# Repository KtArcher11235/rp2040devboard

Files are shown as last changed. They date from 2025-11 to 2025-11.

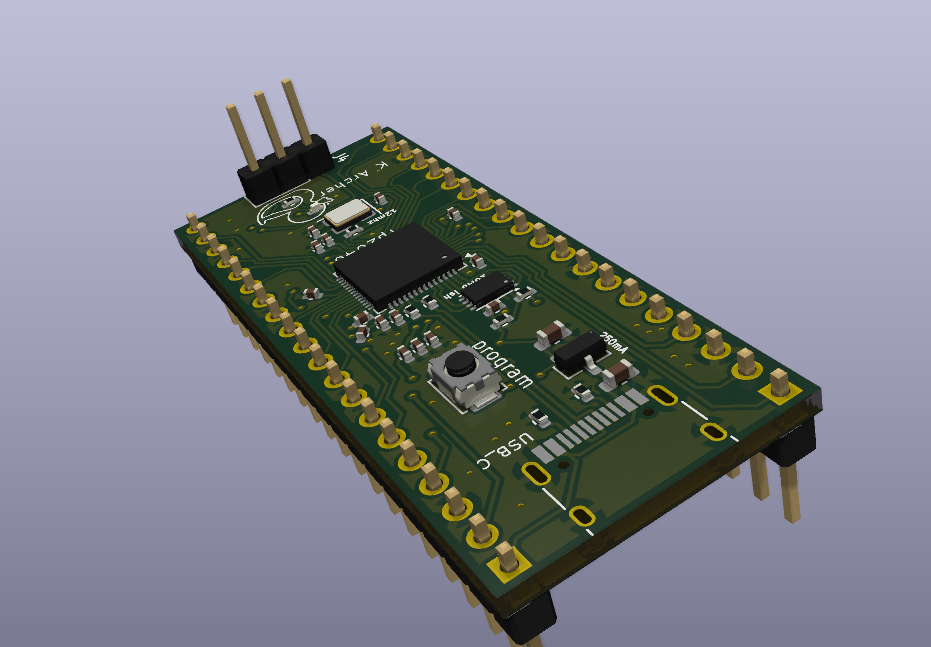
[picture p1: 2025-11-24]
CAD/Screenshot 2025-11-24 150255.png

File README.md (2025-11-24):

# rp2040devboard
a signature devboard based on the rp2040 designed to be as minimal as possible, allowing for expandability through the pins.



## specs
- rp2040
- 16 MiB Flash
- LED on gipo25
- 12 MHz crystal
- USB interface with voltage regulator

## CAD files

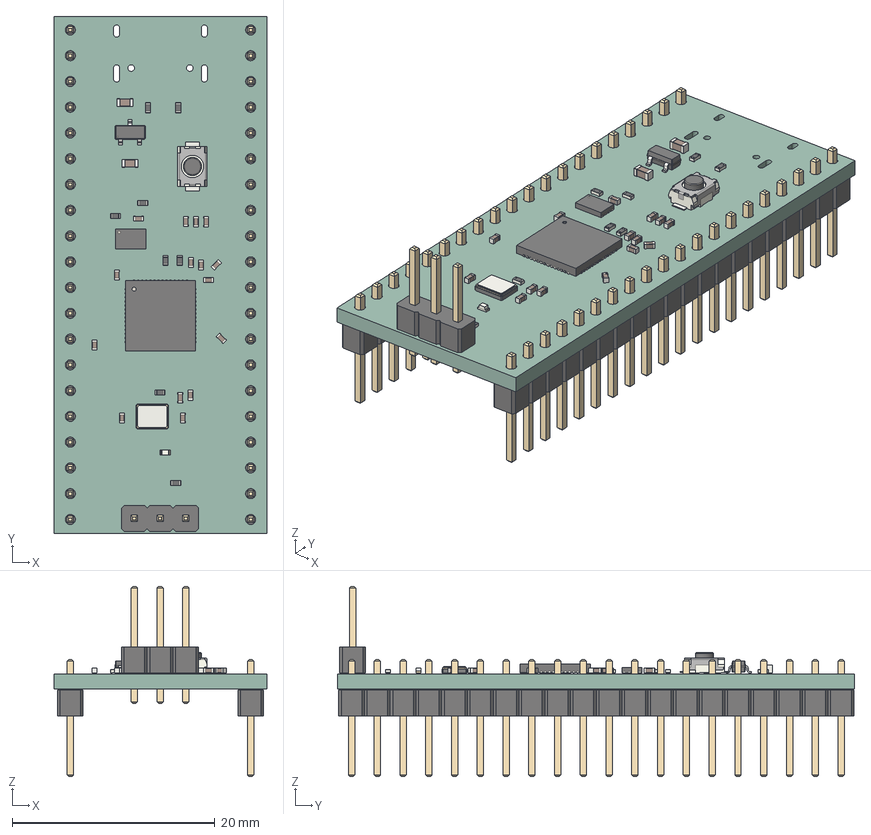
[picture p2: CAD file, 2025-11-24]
CAD/devboard.step
21.0 x 51.0 x 18.8 mm
C_0603_1608Metric x 2
C_0402_1005Metric x 15
LED_0402_1005Metric
SOT-23
R_0402_1005Metric x 8
QFN-56-1EP_7x7mm_P0.4mm_EP3.2x3.2mm
Crystal_SMD_3225-4Pin_3.2x2.5mm
SW_Push_SPST_NO_Alps_SKRK
Winbond_USON-8-1EP_3x2mm_P0.5mm_EP0.2x1.6mm
PinHeader_1x03_P2.54mm_Vertical
PinHeader_1x20_P2.54mm_Vertical x 2
devboard_PCB

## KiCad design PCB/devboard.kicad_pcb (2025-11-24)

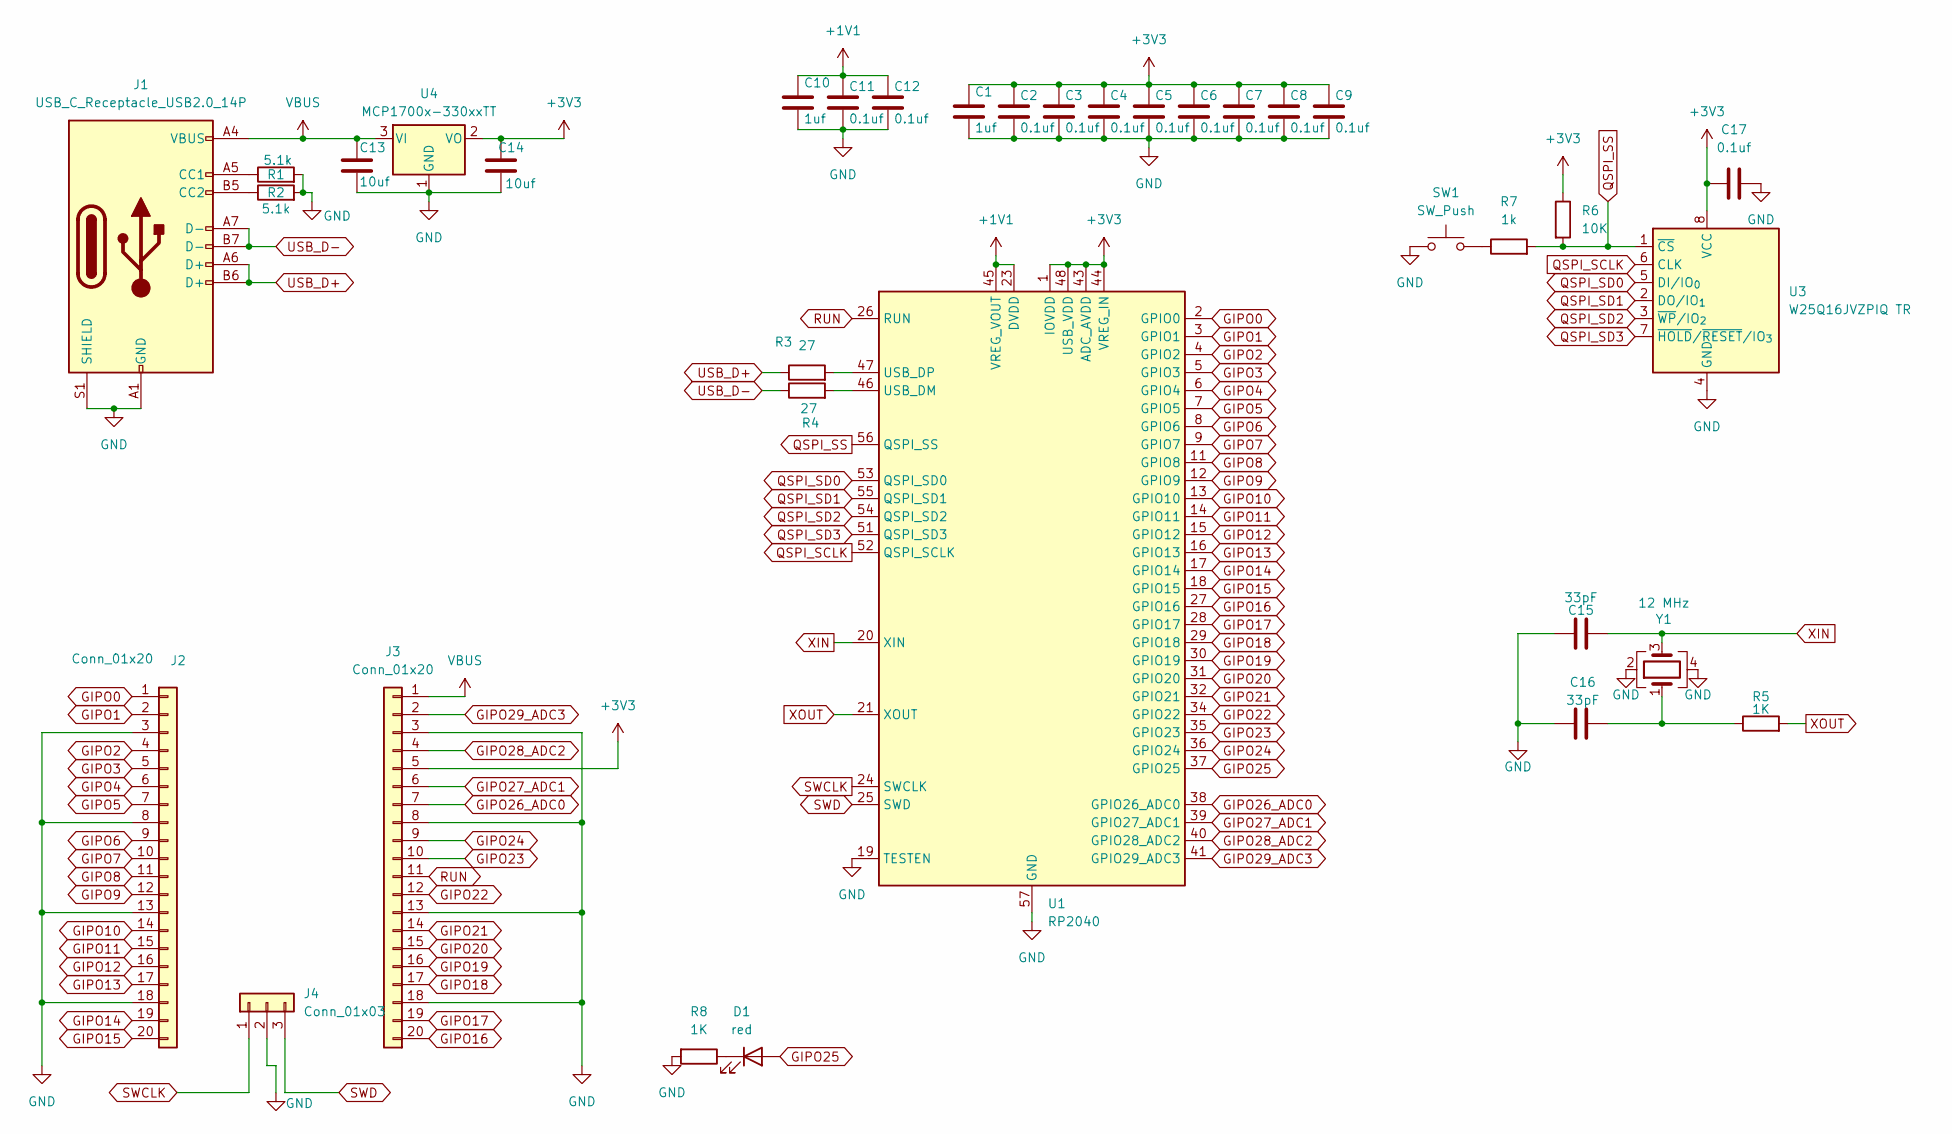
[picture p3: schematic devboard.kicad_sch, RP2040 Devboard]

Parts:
C1, C10: 1uf; C_0402_1005Metric
C2, C3, C4, C5, C6, C7, C8, C9, C11, C12, C17: 0.1uf; C_0402_1005Metric
C13, C14: 10uf; C_0603_1608Metric
C15, C16: 33pF; C_0402_1005Metric
D1: red; LED_0402_1005Metric
J1: USB_C_Receptacle_USB2.0_14P; USB_C_Receptacle_HRO_TYPE-C-31-M-12
J2, J3: Conn_01x20; PinHeader_1x20_P2.54mm_Vertical
J4: Conn_01x03; PinHeader_1x03_P2.54mm_Vertical
R1, R2: 5.1k; R_0402_1005Metric
R3, R4: 27; R_0402_1005Metric
R5, R8: 1K; R_0402_1005Metric
R6: 10K; R_0402_1005Metric
R7: 1k; R_0402_1005Metric
SW1: SW_Push; SW_Push_SPST_NO_Alps_SKRK
U1: RP2040; QFN-56-1EP_7x7mm_P0.4mm_EP3.2x3.2mm
U3: W25Q16JVZPIQ TR; Winbond_USON-8-1EP_3x2mm_P0.5mm_EP0.2x1.6mm
U4: MCP1700x-330xxTT; SOT-23
Y1: 12 MHz; Crystal_SMD_3225-4Pin_3.2x2.5mm

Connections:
+1V1: C10.1, C11.1, C12.1, U1.23 (DVDD), U1.45 (VREG_VOUT), U1.50 (DVDD)
+3V3: C1.1, C2.1, C3.1, C4.1, C5.1, C6.1, C7.1, C8.1, C9.1, C14.1, C17.1, J3.5 (Pin_16), R6.1, U1.1 (IOVDD), U1.10 (IOVDD), U1.22 (IOVDD), U1.33 (IOVDD), U1.42 (IOVDD), U1.43 (ADC_AVDD), U1.44 (VREG_IN), U1.48 (USB_VDD), U1.49 (IOVDD), U3.8 (VCC), U4.2 (VO)
GIPO0: J2.1, U1.2 (GPIO0)
GIPO1: J2.2, U1.3 (GPIO1)
GIPO2: J2.4, U1.4 (GPIO2)
GIPO3: J2.5, U1.5 (GPIO3)
GIPO4: J2.6, U1.6 (GPIO4)
GIPO5: J2.7, U1.7 (GPIO5)
GIPO6: J2.9, U1.8 (GPIO6)
GIPO7: J2.10, U1.9 (GPIO7)
GIPO8: J2.11, U1.11 (GPIO8)
GIPO9: J2.12, U1.12 (GPIO9)
GIPO10: J2.14, U1.13 (GPIO10)
GIPO11: J2.15, U1.14 (GPIO11)
GIPO12: J2.16, U1.15 (GPIO12)
GIPO13: J2.17, U1.16 (GPIO13)
GIPO14: J2.19, U1.17 (GPIO14)
GIPO15: J2.20, U1.18 (GPIO15)
GIPO16: J3.20 (Pin_1), U1.27 (GPIO16)
GIPO17: J3.19 (Pin_2), U1.28 (GPIO17)
GIPO18: J3.17 (Pin_4), U1.29 (GPIO18)
GIPO19: J3.16 (Pin_5), U1.30 (GPIO19)
GIPO20: J3.15 (Pin_6), U1.31 (GPIO20)
GIPO21: J3.14 (Pin_7), U1.32 (GPIO21)
GIPO22: J3.12 (Pin_9), U1.34 (GPIO22)
GIPO23: J3.10 (Pin_11), U1.35 (GPIO23)
GIPO24: J3.9 (Pin_12), U1.36 (GPIO24)
GIPO25: D1.2 (A), U1.37 (GPIO25)
GIPO26_ADC0: J3.7 (Pin_14), U1.38 (GPIO26_ADC0)
GIPO27_ADC1: J3.6 (Pin_15), U1.39 (GPIO27_ADC1)
GIPO28_ADC2: J3.4 (Pin_17), U1.40 (GPIO28_ADC2)
GIPO29_ADC3: J3.2 (Pin_19), U1.41 (GPIO29_ADC3)
GND: C1.2, C2.2, C3.2, C4.2, C5.2, C6.2, C7.2, C8.2, C9.2, C10.2, C11.2, C12.2, C13.2, C14.2, C15.1, C16.1, C17.2, J1.A1 (GND), J1.A12 (GND), J1.B1 (GND), J1.B12 (GND), J1.S1 (SHIELD), J2.3, J2.8, J2.13, J2.18, J3.3 (Pin_18), J3.8 (Pin_13), J3.13 (Pin_8), J3.18 (Pin_3), J4.2, R1.2, R2.2, R8.2, SW1.1, U1.19 (TESTEN), U1.57 (GND), U3.4 (GND), U4.1 (GND), Y1.2, Y1.4
unnamed: C16.2, R5.1, Y1.1
unnamed: D1.1 (K), R8.1
unnamed: J1.A5 (CC1), R1.1
unnamed: J1.B5 (CC2), R2.1
unnamed: R7.1, SW1.2
unnamed: R4.2, U1.46 (USB_DM)
unnamed: R3.2, U1.47 (USB_DP)
QSPI_SCLK: U1.52 (QSPI_SCLK), U3.6 (CLK)
QSPI_SD0: U1.53 (QSPI_SD0), U3.5 (DI/IO_{0})
QSPI_SD1: U1.55 (QSPI_SD1), U3.2 (DO/IO_{1})
QSPI_SD2: U1.54 (QSPI_SD2), U3.3 (~WP/IO_{2})
QSPI_SD3: U1.51 (QSPI_SD3), U3.7 (~HOLD/~RESET/IO_{3})
QSPI_SS: R6.2, R7.2, U1.56 (QSPI_SS), U3.1 (~CS)
RUN: J3.11 (Pin_10), U1.26 (RUN)
SWCLK: J4.1, U1.24 (SWCLK)
SWD: J4.3, U1.25 (SWD)
USB_D+: J1.A6 (D+), J1.B6 (D+), R3.1
USB_D-: J1.A7 (D-), J1.B7 (D-), R4.1
VBUS: C13.1, J1.A4 (VBUS), J1.A9 (VBUS), J1.B4 (VBUS), J1.B9 (VBUS), J3.1 (Pin_20), U4.3 (VI)
XIN: C15.2, U1.20 (XIN), Y1.3
XOUT: R5.2, U1.21 (XOUT)

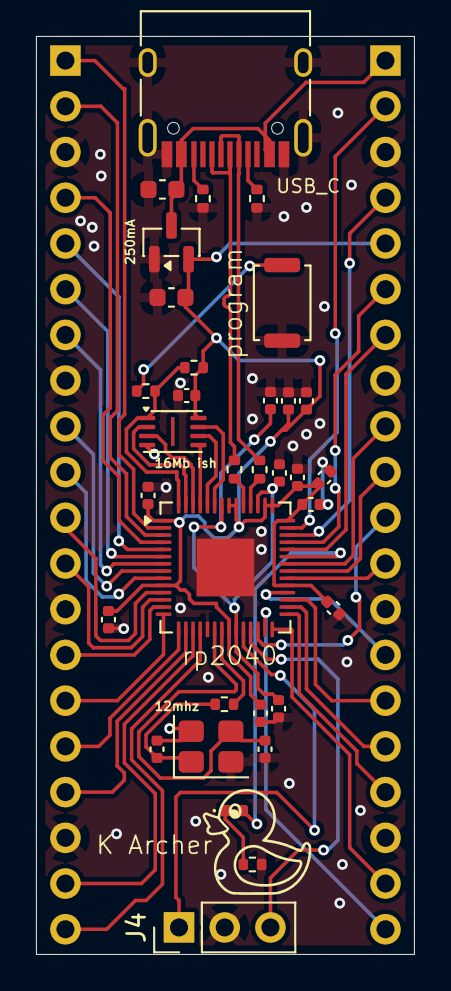
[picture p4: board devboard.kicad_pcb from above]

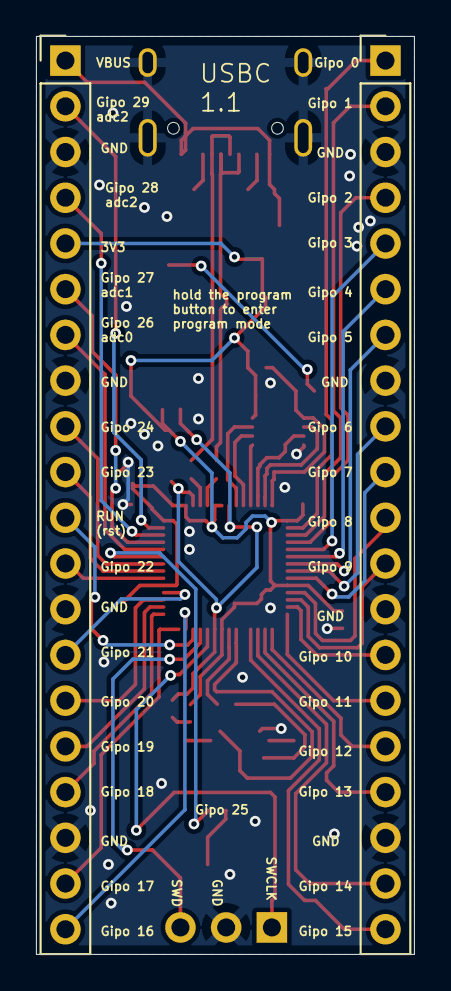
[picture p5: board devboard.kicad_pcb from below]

Board: 2 copper layers, 21.0 x 51.0 mm, 35 parts (2 on the bottom side), 54 nets.

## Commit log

2025-11-24 Add initial devboard CAD, PCB, and firmware files
    Added STEP model, KiCad PCB, schematic, project, and WRL files for the devboard hardware. Included a firmware Python file, gerber outputs, and a screenshot. Updated README.md to reflect new files.
    [devboard.kicad_pcb, devboard.kicad_sch, devboard.step]
2025-11-24 Update README with additional board specifications
    Added specifications for Flash, LED, and crystal.
